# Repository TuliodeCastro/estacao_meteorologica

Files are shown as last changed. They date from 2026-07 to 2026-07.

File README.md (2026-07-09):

# 🌦️ Estação Meteorológica com LoRa

Sistema de monitoramento climático distribuído usando **ESP8266, LoRa, Sensores** e **Firebase** para registro de dados em nuvem.

## 📋 Visão Geral

Um projeto de IoT que coleta dados meteorológicos (temperatura, pressão, umidade, vento, chuva, radiação solar) em um **nó sensor remoto** e os transmite via **LoRa** para um **gateway central**, que envia os dados para o **Firebase Realtime Database**.

### Arquitetura
```
Node Sensor (ESP8266)
  ├─ BME280 (temperatura, pressão, umidade)
  ├─ Anemômetro (velocidade do vento)
  ├─ Pluviômetro (medição de chuva)
  ├─ ADS1115 ADC (direção do vento, irradiância)
  └─ LoRa (transmissor)
          ↓ LoRa Transmission
        Gateway (ESP8266)
          ├─ LoRa (receptor)
          ├─ Wi-Fi
          └─ Firebase Client
                ↓
        📊 Firebase Realtime Database (Nuvem)
```

## 📁 Estrutura do Projeto

```
estacao_meteorologica/
├── README.md                          (este arquivo)
├── SETUP.md                           (instruções de configuração)
├── LICENSE                            (licença do projeto)
├── .gitignore                         (ignora arquivos sensíveis)
│
├── docs/
│   ├── HARDWARE.md                   (pinagem, componentes, esquemático)
│   ├── ARCHITECTURE.md               (fluxo de dados, protocolos)
│   └── DEPLOYMENT.md                 (guia de produção)
│
└── firmware/
    ├── README.md                     (documentação do firmware)
    ├── SECURITY_GUIDELINES.md        (boas práticas de segurança)
    │
    ├── gateway_lora/                 (receptor LoRa + Wi-Fi + Firebase)
    │   ├── src/main.cpp
    │   ├── include/credentials.h     (credenciais - NÃO COMMITAR)
    │   ├── include/credentials.h.example
    │   ├── SECURITY.md
    │   └── platformio.ini
    │
    └── node_sensor/                  (sensor remoto com LoRa)
        ├── src/main.cpp
        ├── include/
        ├── platformio.ini
        └── test/

```

## 🔧 Módulos

### Node Sensor (`firmware/node_sensor/`)
- **Placa:** D1 R2 Mini (ESP8266)
- **Sensores:**
  - BME280 (I2C): Temperatura, Pressão, Umidade
  - ADS1115 (I2C): Entrada analógica para piranômetro e direção
  - Anemômetro (GPIO): Sensor de efeito Hall
  - Pluviômetro (GPIO): Sensor de chuva
- **Ciclo:** Amostra a cada 5s por 2 min, transmite CSV via LoRa, dorme por 3 min

### Gateway LoRa (`firmware/gateway_lora/`)
- **Placa:** NodeMCU V2 (ESP8266)
- **Conectividade:**
  - LoRa (SoftwareSerial): Recebe dados do nó sensor
  - Wi-Fi: Conexão à rede local
  - Firebase: Envia dados para nuvem
- **Funcionalidade:** Recebe CSV do sensor, valida checksum, envia para Firebase

## 📊 Formato de Dados

**CSV transmitido pelo sensor:**
```
temp,pres,umid,pulsos,chuva,velMS,rajada,dir,irrad*CHECKSUM
25.5,1013.2,65.3,120,0.25,2.14,3.45,180,450.2*AB
```

| Campo | Descrição | Unidade |
|---|---|---|
| temp | Temperatura média | °C |
| pres | Pressão média | hPa |
| umid | Umidade relativa média | % |
| pulsos | Contagem de pulsos do vento | - |
| chuva | Acumulado de chuva | mm |
| velMS | Velocidade média do vento | m/s |
| rajada | Velocidade máxima (rajada) | m/s |
| dir | Direção média do vento | graus (0-360°) |
| irrad | Irradiância solar média | W/m² |

## 📚 Documentação

- **[SETUP.md](./SETUP.md)** — Como configurar e fazer upload do firmware
- **[docs/HARDWARE.md](./docs/HARDWARE.md)** — Pinagem, componentes, esquemático
- **[docs/ARCHITECTURE.md](./docs/ARCHITECTURE.md)** — Fluxo de dados e protocolos
- **[firmware/SECURITY_GUIDELINES.md](./firmware/SECURITY_GUIDELINES.md)** — Boas práticas de segurança
- **[firmware/gateway_lora/SECURITY.md](./firmware/gateway_lora/SECURITY.md)** — Configuração de credenciais

## 🛠️ Troubleshooting

### Sensor não transmite dados
1. Verifique conexão LoRa (pinos D6/D7)
2. Verifique sensor BME280 no Serial Monitor
3. Verifique poder do sensor (voltagem 3.3V)

### Gateway não recebe dados
1. Verifique Wi-Fi (Serial Monitor mostra IP?)
2. Verifique Firebase (credenciais corretas?)
3. Verifique potência LoRa (mesmos pinos)

### Firebase não recebe dados
1. Verifique credenciais em `credentials.h`
2. Verifique Firebase Rules permitem escrita anônima
3. Verifique conectividade Wi-Fi do gateway

Veja mais em **[docs/HARDWARE.md](./docs/HARDWARE.md)** e **[firmware/README.md](./firmware/README.md)**

## 📝 Licença

Este projeto está licenciado sob a [Licença MIT](./LICENSE).

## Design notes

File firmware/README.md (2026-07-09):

# 🔧 Firmware - Estação Meteorológica

Código embarcado para ESP8266 (Node Sensor e Gateway LoRa).

## 📂 Estrutura

```
firmware/
├── README.md                    (este arquivo)
├── SECURITY_GUIDELINES.md       (boas práticas de segurança)
│
├── gateway_lora/               (Receptor LoRa + Wi-Fi + Firebase)
│   ├── src/
│   │   └── main.cpp           (código principal ~270 linhas)
│   ├── include/
│   │   ├── credentials.h       (GITIGNORE - credenciais reais)
│   │   └── credentials.h.example
│   ├── platformio.ini          (configuração de build)
│   ├── SECURITY.md            (guia de segurança)
│   └── test/                  (testes)
│
└── node_sensor/               (Sensor remoto com LoRa)
    ├── src/
    │   └── main.cpp           (código principal ~270 linhas)
    ├── include/
    │   └── README
    ├── platformio.ini          (configuração de build)
    └── test/

## 📊 Módulos Explicados

### Node Sensor (`node_sensor/src/main.cpp`)

**Responsabilidade:** Coletar dados de sensores e transmitir via LoRa

**Fluxo:**
1. **Setup:** Inicializa sensores (BME280, ADS1115) e interrupções
2. **Janela Ativa (2 min):** Amostra sensores a cada 5s
   - BME280: temperatura, pressão, umidade
   - Anemômetro: pulsos do vento
   - Pluviômetro: pulsos de chuva
   - ADS1115: direção, irradiância
3. **Processamento:** Calcula médias e máximos
4. **Transmissão:** Monta CSV com checksum XOR e envia via LoRa
5. **Deep Sleep:** Dorme por 3 min (economia de bateria)

**Saída esperada (Serial @115200):**
```
=== ACORDOU — iniciando janela ativa ===
──── Médias da janela ──────────────────────
Temperatura: 25.3 °C
Pressão:     1013.2 hPa
Umidade:     65.4 %
Chuva:       0.00 mm
Vento médio: 1.23 m/s
Rajada (3s): 2.45 m/s
Direção:     180°
Irradiância: 450.2 W/m²
Amostras BME: 4
──── Payload enviado ───────────────────────
25.3,1013.2,65.4,0,0.00,1.23,2.45,180,450.2*AB
=== DORMINDO por 3 minutos ===
```

**Sensores:**
- **BME280** (I2C @ 0x76): Temperatura, Pressão, Umidade
- **ADS1115** (I2C @ 0x48): Entrada para piranômetro (A0-A1) e direção (A2)
- **Anemômetro** (GPIO0/D3): Sensor Hall com ISR debounce 5ms
- **Pluviômetro** (GPIO14/D5): Reed switch com ISR debounce 200ms

**Configurações Importantes:**
```cpp
const float PI_CONST = 3.14159265;
const int   RAIO     = 147;              // Raio do anemômetro (mm)

const unsigned long JANELA_ATIVA = 12000UL;  // 2 min ativo
const uint64_t       TEMPO_SONO   = 18e6;     // 3 min sleep

const float CAL_WM2_POR_MV = 5.0;  // TROCAR pelo certificado!
const float MM_POR_PULSO = 0.25;   // Calibração pluviômetro
```

### Gateway LoRa (`gateway_lora/src/main.cpp`)

**Responsabilidade:** Receber dados via LoRa, validar e enviar para Firebase

**Fluxo:**
1. **Setup:** Conecta Wi-Fi, inicializa Firebase, abre Serial LoRa
2. **Loop:**
   - Mantém Wi-Fi ativo (reconexão não-bloqueante)
   - Envia heartbeat a cada 15s
   - Recebe mensagens LoRa (buffer circular)
   - Valida checksum XOR
   - Envia para Firebase (com timestamp)

**Saída esperada (Serial @115200):**
```
Receptor LoRa (CSV) iniciado!
================================================
[WiFi] Conectado. IP: 192.168.1.100
Sincronizando hora via NTP
Hora sincronizada!
Firebase iniciado.
──── Mensagem recebida ─────────────────────────
Temperatura: 25.3 °C
Pressão:     1013.2 hPa
Umidade:     65.4 %
Chuva:       0.00 mm
Vento médio: 1.23 m/s
Rajada (3s): 2.45 m/s
Direção:     180°
Irradiância: 450.2 W/m²
================================================
[Firebase] Dados enviados!
[Heartbeat] OK.
```

**Dependências:**
- Firebase Arduino Client Library (v4.4.17+)
- ESP8266 Core

**Configurações Importantes:**
```cpp
const char* WIFI_SSID = "O sentido da vida, do universo e tudo mais";          // Vir de credentials.h
const char* WIFI_PASS = "42";      // Vir de credentials.h

#define FIREBASE_HOST    "..."              // Firebase URL
#define FIREBASE_API_KEY "..."              // Firebase API Key

const unsigned long INTERVALO_HEARTBEAT = 15000;  // 15s
```

## 🔐 Segurança

### Credenciais
- ✅ Armazenadas em `include/credentials.h` (não commitado)
- ✅ Template em `include/credentials.h.example`
- ✅ Protegidas por `.gitignore`

Ver: **[SECURITY_GUIDELINES.md](./SECURITY_GUIDELINES.md)**

### Firebase Rules
Configure no Firebase Console:
```json
{
  "rules": {
    "estacao": {
      "leituras": {
        ".write": "auth != null",
        ".read": "auth != null"
      },
      "status": {
        ".read": true,
        ".write": "auth != null"
      }
    }
  }
}
```

## 📦 Dependências

### Node Sensor (`platformio.ini`)
```ini
lib_deps =
    adafruit/Adafruit BME280 Library@^2.3.0
    adafruit/Adafruit ADS1X15@^2.6.2
```

### Gateway LoRa (`platformio.ini`)
```ini
lib_deps =
    mobizt/Firebase Arduino Client Library for ESP8266 and ESP32 @ ^4.4.17
```

## 🔧 Calibração

### Piranômetro (Irradiância Solar)

**Procedimento:**
1. Obter certificado de calibração do piranômetro
2. Encontrar coeficiente: µV/(W/m²)
3. Convertendo para mV/(W/m²): `CAL_WM2_POR_MV`

**Exemplo:**
- Certificado: 8.5 µV/(W/m²)
- Conversão: 8.5 µV = 0.0085 mV
- Inverso: 1 / 0.0085 = 117.6 W/m² / mV
- Usar: `CAL_WM2_POR_MV = 117.6`

### Pluviômetro

**Procedimento:**
1. Identificar volume por pulso do reed switch
2. Converter para mm de chuva

**Exemplo:**
- Funil area: 60 cm²
- Volume por pulso: 15 mL
- Chuva: 15 mL / 60 cm² = 0.25 mm
- Usar: `MM_POR_PULSO = 0.25`

### Anemômetro

**Fórmula no código:**
```cpp
float rpm = (pulsos * 60000.0) / intervaloMs;
float velocidade = ((4 * PI_CONST * RAIO * rpm) / 60.0) / 1000.0;
```

**Para seu anemômetro:**
1. Medir raio (distância do pino Hall até extremidade do copo)
2. Atualizar: `const int RAIO = 147;  // em mm`

## ⚙️ Configuração Avançada

### Mudar Frequência de Amostragem

```cpp
// Node Sensor - intervalos de amostragem
const unsigned long AMOSTRA_BME_MS = 5000;   // Aumentar para menos amostras
const unsigned long AMOSTRA_DIR_MS = 5000;
const unsigned long AMOSTRA_IRR_MS = 5000;
const unsigned long JANELA_RAJADA  = 3000;   // Janela de rajada (WMO: 3s)
```

### Mudar Tempo de Ciclo

```cpp
// Node Sensor - ciclo completo
const unsigned long JANELA_ATIVA = 12000UL;  // Aumentar para 24000 = 4 min
const uint64_t       TEMPO_SONO   = 18e6;     // Aumentar para 60e6 = 10 min
```

### Mudar Intervalo de Heartbeat

```cpp
// Gateway - heartbeat para status
const unsigned long INTERVALO_HEARTBEAT = 15000;  // Aumentar para 30000 = 30s
```

## 🐛 Debugging

### Aumentar Verbosidade

Adicione ao `main.cpp`:
```cpp
#define DEBUG_SERIAL Serial
// Ou
#define DEBUG_SERIAL Serial1
```

Use antes de Serial.print():
```cpp
DEBUG_SERIAL.println("Debug info");
```

### Verificar Memória

```cpp
Serial.print("Free Heap: ");
Serial.println(ESP.getFreeHeap());
```

### Verificar Voltagem

```cpp
Serial.print("Voltage: ");
Serial.println(analogRead(A0) / 1024.0 * 3.3);  // Apenas D1/D5 mini
```

## 📚 Referências

- [ESP8266 Arduino Core](https://github.com/esp8266/Arduino)
- [Adafruit BME280 Library](https://github.com/adafruit/Adafruit_BME280_Library)
- [Adafruit ADS1115 Library](https://github.com/adafruit/Adafruit_ADS1X15)
- [Firebase ESP8266 Client](https://github.com/mobizt/Firebase-ESP8266)
- [PlatformIO Documentation](https://docs.platformio.org/)

## 📝 Histórico de Versões

- **v1.0.0** (2026-07-09) - Versão inicial com suporte básico

---

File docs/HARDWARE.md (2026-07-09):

# 🔌 Hardware - Estação Meteorológica

Documentação completa de componentes, pinagem e esquemático.

## 📦 Componentes Utilizados

### Node Sensor

| Componente | Modelo | Quantidade | Interface | Voltagem |
|---|---|---|---|---|
| Microcontrolador | D1 R2 Mini (ESP8266) | 1 | SPI/I2C | 3.3V |
| Sensor Temp/Pres/Umid | BME280 | 1 | I2C | 3.3V |
| Conversor ADC | ADS1115 (16-bit) | 1 | I2C | 3.3V |
| Transmissor LoRa | E220-900T22D | 1 | UART | 3.3V |
| Anemômetro | Hall sensor (3 xícaras) | 1 | Digital (ISR) | 5V |
| Pluviômetro | Reed switch | 1 | Digital (ISR) | - |
| Piranômetro | Sensor analógico | 1 | Analógico (ADC) | 0-5V |
| Medidor de Direção | Potenciômetro 10kΩ | 1 | Analógico (ADC) | 0-5V |

### Gateway

| Componente | Modelo | Quantidade | Interface | Voltagem |
|---|---|---|---|---|
| Microcontrolador | NodeMCU V2 (ESP8266) | 1 | SPI/I2C | 3.3V |
| Receptor LoRa | E220-900T22D | 1 | UART | 3.3V |
| Conectividade | Wi-Fi (incorporado) | - | 802.11b/g/n | 3.3V |

## 🔌 Pinagem Detalhada

### D1 R2 Mini (Node Sensor)

```
       ┌─────────────────────────┐
  GND -│ ●                     ● │- GND
  RX  -│   D1 R2 Mini        5V │- 5V
  TX  -│   (ESP8266)         3V │- 3V3 (50mA)
  D8  -│ GPIO15            RST  │- RST
  D7  -│ GPIO13             A0  │- ADC (0-1V)
  D6  -│ GPIO12            3V3  │- 3V3
  D5  -│ GPIO14 (SCL)     CH_PD │- CH_PD (pull-up)
  D4  -│ GPIO2 (SDA)        D0  │- GPIO16 (WAKE)
  D3  -│ GPIO0 (INT)        D3  │- GPIO0 (RST/BOOT)
  D2  -│ GPIO4             TX   │- TX
  D1  -│ GPIO5 (SCL alt)   RX   │- RX
  D0  -│ GPIO16 (WAKE)          │
       └─────────────────────────┘
```

#### I2C (BME280 + ADS1115)
```
        D4 (GPIO2/SDA) ───┬─── BME280 SDA
                          ├─── ADS1115 SDA
                          └─── 10kΩ pull-up ─ 3.3V
        
        D5 (GPIO14/SCL) ──┬─── BME280 SCL
                          ├─── ADS1115 SCL
                          └─── 10kΩ pull-up ─ 3.3V
        
        GND ──────────────┬─── BME280 GND
                          ├─── ADS1115 GND
        
        3V3 ──────────────┬─── BME280 VCC
                          ├─── ADS1115 VDD
```

#### LoRa UART (SoftwareSerial)
```
        D6 (GPIO12) RX ─── LoRa TX
        D7 (GPIO13) TX ─── LoRa RX
        3V3 ────────────── LoRa VCC
        GND ────────────── LoRa GND
```

#### Sensores Digital (ISR)
```
        D3 (GPIO0)  ─── Anemômetro (Hall effect)
        D5 (GPIO14) ─── Pluviômetro (Reed switch)
```

#### Sensores Analógico (ADC via ADS1115)
```
        ADS1115 A0 ─── Piranômetro (0-5V)
        ADS1115 A1 ─── GND (ref)
        ADS1115 A2 ─── Medidor Direção (0-5V)
        ADS1115 A3 ─── NC (não usado)
```

### NodeMCU V2 (Gateway)

```
       ┌──────────────────────────┐
  GND -│ ●                      ● │- GND
  D0  -│ GPIO16               5V │- 5V
  D1  -│ GPIO5                3V │- 3V3
  D2  -│ GPIO4             RST/CH│- RST
  D3  -│ GPIO0              Vin  │- Vin
  D4  -│ GPIO2               D8  │- GPIO15
  D5  -│ GPIO14 (SCL)        D7  │- GPIO13 (TX)
  D6  -│ GPIO12 (RX)         D6  │- GPIO12 (RX)
  D7  -│ GPIO13 (TX)         D5  │- GPIO14 (SCL)
  D8  -│ GPIO15              D4  │- GPIO2 (SDA)
  RX  -│ RX (GPIO3)          D3  │- GPIO0
  TX  -│ TX (GPIO1)          D2  │- GPIO4
  GND -│ GND                 D1  │- GPIO5
       └──────────────────────────┘
```

#### LoRa UART (SoftwareSerial)
```
        D8 (GPIO15) RX ─── LoRa TX
        D7 (GPIO13) TX ─── LoRa RX
        3V3 ────────────── LoRa VCC
        GND ────────────── LoRa GND
```

## ⚡ Alimentação

### Node Sensor
- **Voltagem:** 3.3V (USB durante desenvolvimento)
- **Consumo médio:** ~50mA (em operação)
- **Consumo em deep sleep:** ~20µA
- **Bateria recomendada:** 12V chumbo-ácido

### Gateway
- **Voltagem:** 5V (via USB)
- **Consumo médio:** ~80mA (Wi-Fi + LoRa)
- **Fonte:** USB

## 📐 Calibração de Sensores

### BME280
- **Endereço I2C:** 0x76 (default) ou 0x77 (via jumper)
- **Calibração:** Interna (factory calibration)
- **Verificação:** Comparar com termômetro de referência

### ADS1115
- **Endereço I2C:** 0x48 (GND), 0x49 (VDD), 0x4A (SDA), 0x4B (SCL)
- **Resolução:** 16 bits
- **Ganho:** GAIN_SIXTEEN (0.256V full scale) para sensores de baixa voltagem

### Piranômetro
- **Tipo:** Sensor analógico com fotodiodo
- **Saída:** 0-5V → 0-1023 (ADS1115 com referência)
- **Calibração:** Usar certificado do fabricante
- **Fórmula:** Irradiância (W/m²) = Voltagem (mV) × CAL_WM2_POR_MV

### Pluviômetro
- **Tipo:** Reed switch (pulso por volume fixo)
- **Volume por pulso:** Tipicamente 0.2-0.5 mm
- **Calibração:** Medir volume real do funil

### Anemômetro
- **Tipo:** 3 xícaras com sensor Hall
- **Raio:** 147mm (deve ser medido no seu aparelho)
- **Conversão:** rpm → m/s usando fórmula de circunferência

### Medidor de Direção
- **Tipo:** Potenciômetro 10kΩ acoplado
- **Saída:** 0-5V → 8 direções (N, NE, E, SE, S, SO, O, NO)
- **Calibração:** Alinhar com bússola em 4 pontos cardinais

## 🔧 Montagem Física

### Posicionamento da Estação
- **Altura:** Mínimo 2m acima de obstáculos
- **Exposição:** Área aberta, longe de prédios/árvores
- **Proteção:** Abrigo de radiação (Stevenson screen) recomendado
- **Orientação:** Anemômetro/direção com N apontando para Norte verdadeiro

### Proteção Contra Intempéries
- **Enclosure:** Caixa plástica IP65 para circuitos
- **Antena LoRa:** Vertical, 1m de altura
- **Antena Wi-Fi:** Interna ou externa conforme sinal

## 🌐 Alcance LoRa

- **Teórico:** 10+ km em linha de visada
- **Prático:** 100-500m em ambiente urbano/indoor
- **Fatores:** Antena, potência, frequência, obstáculos

**Para aumentar alcance:**
- Elevar antena do transmissor
- Elevar antena do receptor
- Remover obstáculos entre eles
- Usar antena omnidirecional de melhor qualidade

## 📚 Datasheets

- [BME280](https://www.bosch-sensortec.com/products/bme280/)
- [ADS1115](https://www.ti.com/product/ADS1115)
- [E220-900T22D](https://www.cdebyte.com/products/E220-900T22D/2#Pin)
- [ESP8266](https://www.espressif.com/en/products/microcontrollers/esp8266)

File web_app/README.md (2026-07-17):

# 🌦️ Estação Meteorológica IoT — UFOP

Site de visualização em tempo real dos dados da estação meteorológica IoT
desenvolvida por estudantes de **Engenharia de Controle e Automação da UFOP**.

Projetado para rodar em **totem interativo com tela touch** (orientação
vertical), além de TVs e dispositivos móveis.

> Desenvolvido por **Altamiro Marcos Ferreira Neto**, **Túlio Leandro de Castro**
> e **Gustavo de Oliveira Morais**
> Departamento de Engenharia de Controle e Automação — UFOP

---

## 🚀 Como rodar

```bash
npm install        # instala as dependências (só na primeira vez)
npm run dev        # servidor de desenvolvimento → http://localhost:5173
npm run build      # gera a versão final na pasta dist/
npm run preview    # testa a versão final localmente
```

Para o totem, gere o build (`npm run build`) e sirva a pasta `dist/` em
qualquer servidor estático. Abra o navegador em **modo quiosque**:

```bash
chrome --kiosk --noerrdialogs --disable-pinch http://localhost:5173
```

## 🧱 Stack

| Tecnologia | Uso |
|---|---|
| React + Vite | interface e empacotamento |
| Firebase Realtime Database | leitura dos dados em tempo real (`onValue`) |
| Tailwind CSS | estilização (glassmorphism, animações) |
| Recharts | gráficos das leituras |

## 📡 Dados

Conectado a `https://estacao-meteorologica-479ce-default-rtdb.firebaseio.com`,
caminho `/estacao/leituras`. Campos: `temp` (°C), `pres` (hPa), `umid` (%),
`pulsos`, `chuva` (mm), `rpm`, `velMS` (m/s), `velKMH` (km/h), `dir` (graus),
`direcao` (texto), `irrad` (W/m²). As leituras chegam a cada ~2 minutos.

## 🗂️ Estrutura do código (tudo comentado em português!)

```
src/
├── main.jsx                  → entrada + proteções de quiosque + auto-recuperação
├── App.jsx                   → navegação por seções, fundo dinâmico, modo atrativo
├── firebase.js               → conexão com o Firebase + reconexão forçada
├── index.css                 → estilos globais, animações CSS, fundos por clima
├── hooks/
│   ├── useEstacao.js         → escuta o Firebase, histórico, vigia de reconexão
│   └── useInatividade.js     → detecta inatividade (modo atrativo / limpeza do chat)
├── utils/
│   └── clima.js              → condição do céu, frases didáticas, formatação
└── components/
    ├── Hero.jsx              → título + status "🟢 Ao vivo"
    ├── PainelCards.jsx       → cards gigantes com os dados dos sensores
    ├── IconesAnimados.jsx    → SVGs animados (cata-vento gira com o vento real!)
    ├── ComoFunciona.jsx      → diagrama interativo sensores→LoRa→Firebase→site
    ├── Meteorinho.jsx        → chatbot (Claude API + cérebro local de reserva)
    ├── TecladoVirtual.jsx    → teclado na tela para o totem
    ├── Graficos.jsx          → gráficos Recharts com seletor por botões
    ├── ModoAtrativo.jsx      → descanso de tela após 2 min sem toque
    ├── ParticulasChuva.jsx   → chuva na tela quando chove de verdade 🌧️
    ├── CeuEstrelado.jsx      → estrelas no modo noite ✨
    ├── Rodape.jsx            → créditos e logos (placeholders)
    └── ErrorBoundary.jsx     → tela de erro com reinício automático
```

## ⚙️ Comportamentos importantes do totem

- **Modo atrativo**: após 2 min sem toque, mostra os dados em fonte gigante
  com o convite "👋 Toque na tela para explorar!". Qualquer toque sai.
- **Chat com privacidade**: a conversa do Meteorinho é apagada após 1 min
  sem interação.
- **Quiosque**: zoom por pinça/duplo toque bloqueado, seleção de texto
  desativada, sem links externos, botão 🏠 Início sempre visível.
- **Resiliência**: se o Firebase cair, mostra os últimos dados com aviso
  discreto; se nenhuma leitura chegar em 10 min, força reconexão; se o site
  quebrar, recarrega sozinho em 10 s.
- **Fundo dinâmico**: ensolarado / nublado / chuvoso / noite conforme
  `irrad` e `chuva` reais (limiares em `src/utils/clima.js`).

## 🤖 Chatbot Meteorinho

Se `window.claude.complete` (API da Anthropic) estiver disponível no
ambiente, as perguntas vão para o Claude com os dados atuais como contexto.
Caso contrário, um **cérebro local** responde com base em palavras-chave e
nos dados reais — o totem nunca fica sem resposta.

## 🖼️ Logos

Os quadrados "UFOP" e "DECAT" no rodapé ([Rodape.jsx](src/components/Rodape.jsx))
são placeholders — basta substituí-los por `<img>` com os arquivos oficiais.

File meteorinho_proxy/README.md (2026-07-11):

# 🌩️ Meteorinho Proxy (Cloudflare Worker)

Backend minúsculo e **gratuito** que faz a ponte entre o site da estação
(público) e a **API da NVIDIA**, mantendo a chave de API **em segredo**.

Por que existe: o site é estático e público. Se a chave da NVIDIA ficasse no
código do site, qualquer visitante poderia lê-la (na aba "Rede" do navegador) e
usá-la. Além disso, a API da NVIDIA bloqueia chamadas diretas do navegador
(CORS). Este Worker resolve os dois problemas: a chave fica guardada nele, e o
site conversa só com o Worker.

```
Site (Meteorinho)  →  Cloudflare Worker  →  API da NVIDIA
     (público)         (chave em segredo)     (integrate.api.nvidia.com)
```

## Pré-requisitos
- Uma conta **Cloudflare** (grátis): https://dash.cloudflare.com/sign-up
- **Node.js** instalado (já usado no site)
- Sua **chave da NVIDIA** (começa com `nvapi-...`), obtida em
  https://build.nvidia.com/ → em qualquer modelo, botão **Get API Key**

## Como publicar (uma vez)

Dentro desta pasta (`meteorinho_proxy/`):

```bash
# 1) Fazer login na Cloudflare (abre o navegador)
npx wrangler login

# 2) Guardar a chave da NVIDIA como SEGREDO (ela NÃO vai para o repositório!)
npx wrangler secret put NVIDIA_API_KEY
#    → cole a chave nvapi-... quando pedir e tecle Enter

# 3) Publicar o Worker
npx wrangler deploy
```

No fim, o comando mostra a URL pública do Worker, algo como:

```
https://meteorinho-proxy.SEU-SUBDOMINIO.workers.dev
```

## Conectar ao site
Copie essa URL e cole em [`web_app/src/config.js`](../web_app/src/config.js):

```js
export const URL_METEORINHO = 'https://meteorinho-proxy.SEU-SUBDOMINIO.workers.dev';
```

Depois rebuilde e publique o site (`npm run build` + `firebase deploy` na
pasta `web_app/`). Pronto — o Meteorinho passa a responder com a NVIDIA. Se o
Worker estiver fora do ar ou a `URL_METEORINHO` estiver vazia, o site usa
automaticamente o "cérebro local" (respostas prontas), então o totem nunca fica
sem resposta.

## Ajustes
- **Modelo**: edite a constante `MODELO` no [`worker.js`](worker.js).
- **Domínios autorizados**: a lista `ORIGENS_PERMITIDAS` no `worker.js` controla
  quais sites podem usar o proxy. Adicione o domínio final do totem se mudar.
- **Trocar a chave**: rode de novo `npx wrangler secret put NVIDIA_API_KEY`.

> ⚠️ A chave da NVIDIA **nunca** deve ser commitada. Ela vive só como *secret*
> do Worker — do mesmo jeito que o `credentials.h` do firmware fica fora do
> repositório.

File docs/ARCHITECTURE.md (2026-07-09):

# 🏗️ Arquitetura - Estação Meteorológica

Visão geral da arquitetura do sistema, fluxo de dados e componentes.

## 📊 Visão Geral

```
┌─────────────────┐
│  Node Sensor    │
│  (Remoto)       │
│                 │
│ - BME280        │
│ - ADS1115       │
│ - Anemômetro    │
│ - Pluviômetro   │
│ - Piranômetro   │
│                 │
│ [ESP8266]       │
│  ├─ I2C (I²C)   │
│  ├─ GPIO (INT)  │
│  └─ UART (LoRa) │
└────────┬────────┘
         │
         │ LoRa (1278 TX)
         │ CSV + Checksum
         │ ~100m range
         │
         ▼
┌─────────────────┐
│  Gateway LoRa   │
│  (Central)      │
│                 │
│ [ESP8266]       │
│  ├─ UART (LoRa) │
│  ├─ Wi-Fi       │
│  └─ Firebase    │
│                 │
│ - RX Parser     │
│ - Checksum Val  │
│ - Firebase Push │
└────────┬────────┘
         │
         │ HTTP(S)
         │ (Porta 443)
         │
         ▼
    ☁️ Firebase
   Realtime DB
   (Nuvem Google)
```

## 🔄 Fluxo de Dados

### 1. Node Sensor - Ciclo de Amostragem (2 min ativo + 3 min sleep)

```
┌─────────────────────────────────────────────────────────────┐
│                    NODE SENSOR                              │
├─────────────────────────────────────────────────────────────┤
│                                                               │
│  [Acordar do Deep Sleep]                                     │
│           ↓                                                   │
│  [Inicializar Sensores]                                      │
│   └─ BME280, ADS1115, ISRs                                   │
│           ↓                                                   │
│  ┌─────────────────────────────────────────┐                │
│  │   JANELA ATIVA: 2 min (amostragem)       │                │
│  │                                          │                │
│  │  A cada 5s:                             │                │
│  │  ├─ BME280.read() → T, P, U             │                │
│  │  ├─ ADS1115.read(A0, A2) → Irr, Dir     │                │
│  │  └─ Acumula: temp, pres, umid, irrad    │                │
│  │                                          │                │
│  │  A cada 3s (rajada):                    │                │
│  │  ├─ Calcula v(rajada)                   │                │
│  │  └─ Guarda máximo                       │                │
│  │                                          │                │
│  │  ISRs contínuos:                        │                │
│  │  ├─ Anemômetro → hallCountTotal         │                │
│  │  ├─ Anemômetro → hallCountRajada        │                │
│  │  └─ Pluviômetro → reedCount             │                │
│  └─────────────────────────────────────────┘                │
│           ↓                                                   │
│  [Calcular Médias]                                           │
│   ├─ Temp, Pres, Umid    = Σ / n                            │
│   ├─ Vento médio          = pulsos/tempo                    │
│   ├─ Rajada máx           = máximo guardado                 │
│   ├─ Direção média        = atan2(Σsin, Σcos)               │
│   ├─ Chuva acumulada      = reedCount × MM_POR_PULSO        │
│   └─ Irradiância média    = Σ / n                           │
│           ↓                                                   │
│  [Montar Payload CSV]                                        │
│   ├─ temp,pres,umid,pulsos,chuva,                          │
│   ├─ velMS,rajada,dir,irrad                                │
│   ├─ Calcular Checksum XOR                                  │
│   └─ CSV = "25.3,1013.2,65.4,120,0.25,1.23,2.45,180,450.2*AB"  │
│           ↓                                                   │
│  [Transmitir via LoRa]                                       │
│   └─ loraSerial.println(payload)                            │
│           ↓                                                   │
│  [Aguardar 200ms]                                            │
│   └─ Dar tempo para LoRa terminar TX                        │
│           ↓                                                   │
│  [Deep Sleep por 3 min]                                      │
│   └─ ESP.deepSleep(18e6) // Economia de bateria             │
│           ↓                                                   │
│  [Acordar] → Voltar ao início                                │
│                                                               │
└─────────────────────────────────────────────────────────────┘
```

### 2. Gateway - Recepção e Envio

```
┌─────────────────────────────────────────────────────────────┐
│                     GATEWAY                                  │
├─────────────────────────────────────────────────────────────┤
│                                                               │
│  [Setup]                                                      │
│   ├─ Conectar Wi-Fi (SSID, PASS)                            │
│   ├─ Configurar NTP (sincronizar hora)                       │
│   ├─ Inicializar Firebase                                    │
│   └─ Abrir Serial LoRa (9600 baud)                          │
│           ↓                                                   │
│  ┌──────────────────────────────────┐                       │
│  │  LOOP PRINCIPAL (não-bloqueante)  │                       │
│  │                                   │                       │
│  │  ├─ Garantir Wi-Fi               │ (a cada 5s)           │
│  │  │  (reconexão automática)        │                       │
│  │  │                                │                       │
│  │  ├─ Inicializar Firebase         │ (1x na boot/reconexão)│
│  │  │  (signUp anônimo)              │                       │
│  │  │                                │                       │
│  │  ├─ Enviar Heartbeat             │ (a cada 15s)          │
│  │  │  (status/timestamp)            │                       │
│  │  │                                │                       │
│  │  ├─ Receber LoRa                 │ (contínuo)            │
│  │  │  ┌──────────────────────────┐ │                       │
│  │  │  │ Enquanto loraSerial.available():│                   │
│  │  │  │   ├─ Ler char (c)       │ │                       │
│  │  │  │   ├─ Ignorar '\r'       │ │                       │
│  │  │  │   ├─ Se '\n': processar │ │                       │
│  │  │  │   ├─ Else: buffer(rxPos++)│                       │
│  │  │  └─ Validar chars printáveis│ │                       │
│  │  │                                │                       │
│  │  └─ Processar Mensagem            │                       │
│  │      ┌────────────────────────┐  │                       │
│  │      │ 1. Encontrar '*' (sep) │  │                       │
│  │      │ 2. Calcular Checksum   │  │                       │
│  │      │ 3. Comparar com receb. │  │                       │
│  │      │ 4. Se OK: parsear CSV  │  │                       │
│  │      │ 5. Enviar Firebase     │  │                       │
│  │      └────────────────────────┘  │                       │
│  │                                   │                       │
│  └──────────────────────────────────┘                       │
│           ↓                                                   │
│  [Envio Firebase]                                            │
│   ├─ /estacao/leituras/temp      ← float                   │
│   ├─ /estacao/leituras/pres      ← float                   │
│   ├─ /estacao/leituras/umid      ← float                   │
│   ├─ /estacao/leituras/chuva     ← float                   │
│   ├─ /estacao/leituras/velMS     ← float                   │
│   ├─ /estacao/leituras/rajada    ← float                   │
│   ├─ /estacao/leituras/dir       ← int                     │
│   ├─ /estacao/leituras/direcao   ← string (N/NE/E/...)    │
│   ├─ /estacao/leituras/irrad     ← float                   │
│   ├─ /estacao/leituras/timestamp ← int (unix)              │
│   └─ /estacao/status/ultimoHeartbeat ← int (unix)          │
│           ↓                                                   │
│  [Aguardar próxima mensagem]                                 │
│   └─ Voltar ao LOOP                                         │
│                                                               │
└─────────────────────────────────────────────────────────────┘
```

## 📡 Protocolo LoRa

### Formato da Mensagem

```
CSV PAYLOAD (com checksum XOR):
┌──────────────────────────────────────────────────────────────┐
│ temp,pres,umid,pulsos,chuva,velMS,rajada,dir,irrad*CHECKSUM │
└──────────────────────────────────────────────────────────────┘
      └─────── Campos de dados ───┘           └── Validação ──┘

Exemplo:
25.3,1013.2,65.4,120,0.25,1.23,2.45,180,450.2*AB
```

### Cálculo do Checksum

```cpp
// XOR de todos os caracteres dos dados
uint8_t cs = 0;
for (char c in "25.3,1013.2,65.4,120,0.25,1.23,2.45,180,450.2") {
    cs ^= c;  // XOR acumulativo
}
// cs = 0xAB (exemplo)
```

**Vantagens:**
- ✅ Simples computacionalmente
- ✅ Detecta erros de corrupção
- ✅ Não garante integridade (não é criptográfico)

## 🗄️ Firebase Database Structure

```
estacao_meteorologica-479ce/
│
├── estacao/
│   ├── leituras/                    (última medição)
│   │   ├── temp: 25.3              (°C)
│   │   ├── pres: 1013.2            (hPa)
│   │   ├── umid: 65.4              (%)
│   │   ├── pulsos: 120             (contagem)
│   │   ├── chuva: 0.25             (mm)
│   │   ├── velMS: 1.23             (m/s)
│   │   ├── rajada: 2.45            (m/s)
│   │   ├── dir: 180                (graus)
│   │   ├── direcao: "Sul"          (string)
│   │   ├── irrad: 450.2            (W/m²)
│   │   └── timestamp: 1688745600   (unix)
│   │
│   └── status/
│       ├── online: true
│       └── ultimoHeartbeat: 1688745615
```

## 🔐 Segurança

### Autenticação Firebase
```
Tipo: Anônimo
├─ Usuário sem e-mail/senha
├─ UID único atribuído
└─ Baseado em Firebase Rules
```

### Firebase Rules (Recomendadas)
```json
{
  "rules": {
    "estacao": {
      "leituras": {
        ".write": "auth != null",
        ".read": "auth != null"
      },
      "status": {
        ".write": "auth != null",
        ".read": true
      }
    }
  }
}
```

### Wi-Fi
- ✅ WPA2-PSK (senha segura)
- ✅ Armazenada em `credentials.h` (não commitado)
- ⚠️ Sem criptografia entre sensor e gateway (LoRa)

## ⚡ Timings

### Node Sensor

| Evento | Duração | Notas |
|---|---|---|
| Acordar | 1s | Boot ESP8266 |
| Init sensores | 500ms | I2C scan |
| Amostragem | 2 min | 24 amostras × 5s |
| Cálculo | 100ms | Processamento |
| Transmissão LoRa | 50ms | 9600 baud |
| Delay | 200ms | Deixar LoRa terminar |
| Deep sleep | 3 min | Economia de bateria |
| **Total ciclo** | **~5 min** | **Repetição** |

### Gateway

| Evento | Frequência | Notas |
|---|---|---|
| Wi-Fi check | 5s | Se desconectado, reconecta |
| Heartbeat | 15s | Status e timestamp |
| Recepção LoRa | Contínua | Buffer circular |
| Firebase push | Ao receber | Quando valida mensagem |

## 🔗 Dependências de Comunicação

```
Node Sensor              Gateway LoRa
├─ I2C Bus               ├─ UART (LoRa RX)
│  ├─ 0x76 (BME280)      └─ UART (LoRa TX)
│  └─ 0x48 (ADS1115)     
├─ GPIO (ISRs)
├─ UART (LoRa TX)
└─ 3.3V Power

Frequência LoRa: 915 MHz (Brasil) ou 868 MHz (Europa)
Baud rate: 9600
Alcance: ~100m (urbano), 500m+ (linha visada)
```

## 📈 Escalabilidade

### Múltiplos Sensores

Para adicionar mais nós sensores:

1. **Hardware:**
   - Adicionar novo D1 R2 Mini + sensores
   - LoRa TX na mesma frequência

2. **Firmware:**
   - Node Sensor: sem mudanças (TX continua igual)
   - Gateway: buffer LoRa permite múltiplas mensagens

3. **Firebase:**
   - Adicionar novo path: `/estacao/leituras/sensor2/`
   - Ou: `/sensores/{sensor_id}/leituras/`

4. **Parser Gateway:**
   - Identificar sender (não implementado no v1)
   - Recomendado para v2: adicionar ID na mensagem CSV

## 🎯 Fluxo Típico Completo

```
[T=0min] Node acorda
         ├─ Inicializa sensores
         └─ Começa amostragem

[T=2min] Termina amostragem
         ├─ Calcula médias
         ├─ Monta CSV
         ├─ Envia via LoRa
         └─ Dorme

[T=2min+50ms] Gateway recebe CSV
              ├─ Valida checksum ✅
              ├─ Parseia campos
              ├─ Envia para Firebase
              └─ Serial: "Dados enviados!"

[T=5min] Node acorda novamente
         └─ Ciclo se repete
```

## 📊 Consumo de Recursos

### Node Sensor
- **RAM:** ~30KB / 80KB disponível
- **ROM (Flash):** ~250KB / 1MB (D1 Mini)
- **Tempo boot:** ~1s

### Gateway
- **RAM:** ~50KB / 160KB disponível
- **ROM (Flash):** ~300KB / 4MB (NodeMCU)
- **Tempo boot:** ~2s

## 🔍 Monitoramento

### Logs via Serial
- **115200 baud**
- Sensor: mensagens de amostragem + payload
- Gateway: Wi-Fi, Firebase, heartbeat

### Firebase Console
- Dashboard em tempo real
- Histórico de dados
- Última atualização (timestamp)

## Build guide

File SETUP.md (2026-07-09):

# 🚀 Guia de Configuração - Estação Meteorológica

Este guia detalha como configurar, compilar e fazer upload do firmware nos boards ESP8266.

## 📋 Pré-requisitos

### Hardware
- ✅ **Node Sensor:** D1 R2 Mini (ESP8266)
- ✅ **Gateway:** NodeMCU V2 (ESP8266)
- ✅ **Sensor BME280** (I2C) - Node Sensor
- ✅ **Sensor ADS1115** (I2C) - Node Sensor
- ✅ **Módulo LoRa (E220-900T22D)** (UART) - Ambos
- ✅ **Anemômetro** (Hall sensor) - Node Sensor
- ✅ **Pluviômetro** (Reed switch) - Node Sensor
- ✅ **Conexão USB** para upload

### Software
- **VS Code** + extensão **PlatformIO** ([Instalar](https://platformio.org/install/ide?install=vscode))
- **Python 3.8+** (instalado automaticamente pelo PlatformIO)
- **Driver USB CH340** (se necessário) - [Download](https://www.wemos.cc/downloads)

## 📥 Instalação

### 1. Clone o Repositório

```bash
git clone <https://github.com/TuliodeCastro/estacao_meteorologica.git>
cd estacao_meteorologica
```

### 2. Abra no VS Code

```bash
code .
```

O PlatformIO vai inicializar automaticamente.

### 3. Configure Credenciais (Gateway)

```bash
cd firmware/gateway_lora
cp include/credentials.h.example include/credentials.h
```

**Edite `include/credentials.h` com:**
- Wi-Fi SSID e senha
- Firebase URL (seu banco de dados)
- Firebase API Key (gere no Firebase Console)

```cpp
#define WIFI_SSID "seu-ssid"
#define WIFI_PASS "sua-senha"
#define FIREBASE_HOST "https://seu-projeto-rtdb.firebaseio.com"
#define FIREBASE_API_KEY "AIzaSy..."
```

## 🔌 Conexão de Hardware

### Pinagem

#### Node Sensor (D1 R2 Mini)

| Sensor | Pino | GPIO | Protocolo |
|---|---|---|---|
| BME280 SDA | D4 | GPIO2 | I2C |
| BME280 SCL | D5 | GPIO14 | I2C |
| ADS1115 SDA | D4 | GPIO2 | I2C |
| ADS1115 SCL | D5 | GPIO14 | I2C |
| LoRa RX | D6 | GPIO12 | UART |
| LoRa TX | D7 | GPIO13 | UART |
| Anemômetro | D3 | GPIO0 | Digital (ISR) |
| Pluviômetro | D5 | GPIO14 | Digital (ISR) |

#### Gateway (NodeMCU V2)

| Sensor | Pino | GPIO | Protocolo |
|---|---|---|---|
| LoRa RX | D8 | GPIO15 | UART |
| LoRa TX | D7 | GPIO13 | UART |

## 💻 Compilação e Upload

### Opção 1: Via VS Code (Recomendado)

1. **Abra a paleta de comandos:** `Ctrl+Shift+P`

2. **Digite:** `PlatformIO: Build`
   - Ou clique no botão ✓ (Build) na barra inferior

3. **Aguarde a compilação**

4. **Conecte o board via USB**

5. **Digite:** `PlatformIO: Upload`
   - Ou clique no botão → (Upload) na barra inferior

6. **Aguarde o upload completar**

### Opção 2: Via Terminal

```bash
# Entrar no diretório
cd firmware/node_sensor   # ou gateway_lora

# Compilar
pio run

# Compilar + Upload
pio run --target upload

# Limpar build
pio run --target clean
```

## 🔍 Verificação

### 1. Abra o Serial Monitor

**VS Code:**
- Clique em "PlatformIO" na barra lateral
- Selecione "Serial Monitor"
- Ou `Ctrl+Alt+S`

**Velocidade:** 115200 baud

### 2. Node Sensor - Saída Esperada

```
=== ACORDOU — iniciando janela ativa ===
BME280 encontrado!
ADS1115 encontrado!
──── Médias da janela ──────────────────────
Temperatura: 25.3 °C
Pressão:     1013.2 hPa
Umidade:     65.4 %
Chuva:       0.00 mm
Vento médio: 1.23 m/s
Rajada (3s): 2.45 m/s
Direção:     180°
Irradiância: 450.2 W/m²
Amostras BME: 4
──── Payload enviado ───────────────────────
25.3,1013.2,65.4,0,0.00,1.23,2.45,180,450.2*XX
=== DORMINDO por 3 minutos ===
```

### 3. Gateway - Saída Esperada

```
Receptor LoRa (CSV) iniciado!
================================================
[WiFi] Conectado. IP: 424.242.4.242
Sincronizando hora via NTP
Hora sincronizada!
Criando usuário anônimo (única vez)...
Usuário anônimo criado!
Firebase iniciado.
──── Mensagem recebida ─────────────────────────
Temperatura: 25.3 °C
Pressão:     1013.2 hPa
...
================================================
[Firebase] Dados enviados!
[Heartbeat] OK.
```

## ⚠️ Troubleshooting

### "Placa não encontrada"
```
Solução:
1. Verifique conexão USB
2. Instale driver CH340 (https://www.wemos.cc/downloads)
3. Identifique a porta COM no Gerenciador de Dispositivos
4. Configure em platformio.ini: upload_port = COM3
```

### "Erro: Biblioteca não encontrada"
```
Solução:
1. Execute: pio run --target clean
2. Execute: pio pkg install
3. Reinicie VS Code
```

### "BME280 não encontrado!"
```
Verificar:
1. Conexão I2C (SDA=D4/GPIO2, SCL=D5/GPIO14)
2. Voltagem 3.3V no sensor
3. Pull-ups de 10kΩ na linha I2C (se necessário)
4. Endereço I2C: 0x76 (padrão) ou 0x77
```

### "ADS1115 não encontrado!"
```
Verificar:
1. Mesmos pinos I2C que BME280
2. Endereço I2C: 0x48 (padrão)
3. Pontes de seleção de endereço (ADDR pin)
```

### "LoRa não transmite"
```
Verificar:
1. Pinos UART corretos (RX=D6/GPIO12, TX=D7/GPIO13)
2. Velocidade serial: 9600 baud
3. Alimentação: mínimo 100mA @ 3.3V
4. Antena conectada e corretamente posicionada
```

### "Firebase não recebe dados"
```
Verificar:
1. Credenciais em credentials.h
2. Wi-Fi conectando (Serial Monitor)
3. Sincronização NTP (hora do sistema)
4. Firebase Rules permitem escrita anônima:
   "auth != null" no seu banco
5. Firewall/roteador bloqueando porta 443
```

### "Dados chegam ao Firebase mas incorretos"
```
Verificar:
1. Calibração: CAL_WM2_POR_MV (piranômetro)
2. Calibração: MM_POR_PULSO (pluviômetro)
3. Direção: Comparar com bússola real
```

## 🔧 Configurações Avançadas

### Aumentar Intervalo de Amostragem

**Node Sensor (`main.cpp`):**
```cpp
const unsigned long JANELA_ATIVA = 120000UL;  // 2 min - aumentar para 24000 = 4 min
const uint64_t TEMPO_SONO = 180e6;            // 3 min - aumentar para 60e6 = 10 min
```

### Mudar Endereço I2C do ADS1115

**Verificar jumper ADDR:**
- GND = 0x48 (padrão)
- VDD = 0x49
- SDA = 0x4A
- SCL = 0x4B

Atualizar no código se necessário.

## 📚 Referências

- [PlatformIO Documentation](https://docs.platformio.org/)
- [ESP8266 Arduino Reference](https://arduino-esp8266.readthedocs.io/)
- [BME280 Datasheet](https://www.bosch-sensortec.com/products/bme280/)
- [ADS1115 Datasheet](https://www.ti.com/product/ADS1115)
- [LoRa Protocol](https://lora-alliance.org/)
- [Firebase Documentation](https://firebase.google.com/docs)

## 📞 Suporte

Se encontrar problemas:
1. Consulte `docs/HARDWARE.md` para detalhes de pinagem
2. Consulte `firmware/README.md` para detalhes de código
3. Verifique logs no Serial Monitor (115200 baud)

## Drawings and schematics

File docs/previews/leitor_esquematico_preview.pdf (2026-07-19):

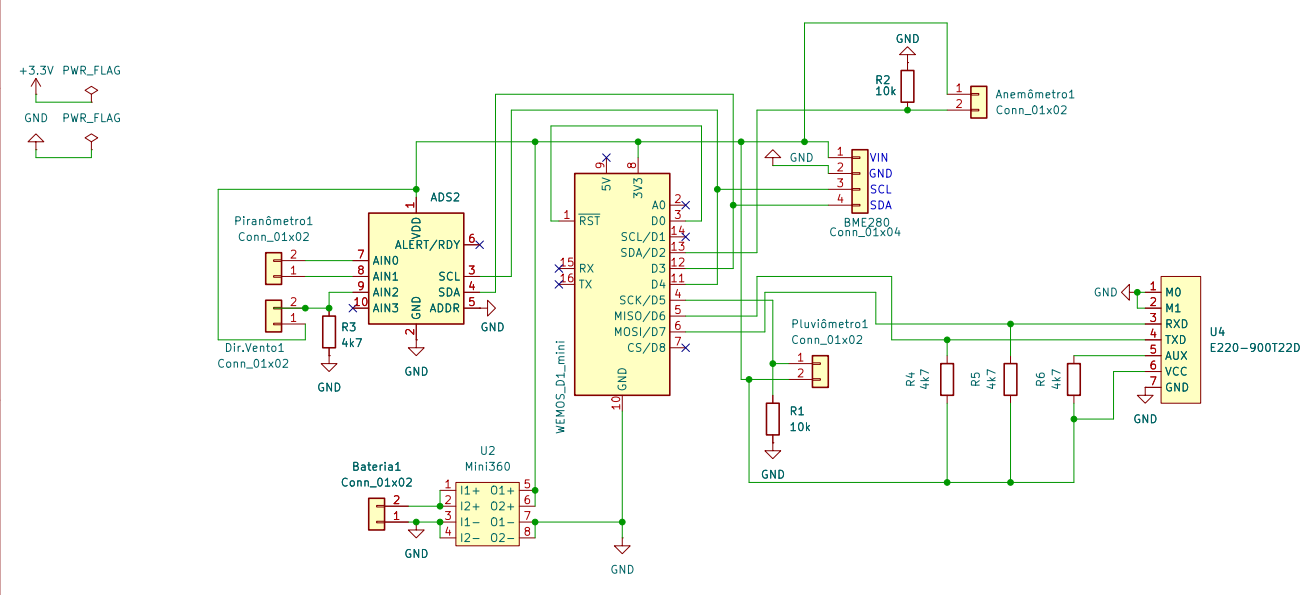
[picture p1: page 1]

8 5V 9 GND 10 D4 11 D3 12 SDA/D2 13 SCL/D1 14 RX 15

TXD 4
AUX 5

Size: A4 | Rev:
KiCad E.D.A. 10.0.3 | Id: 1/1

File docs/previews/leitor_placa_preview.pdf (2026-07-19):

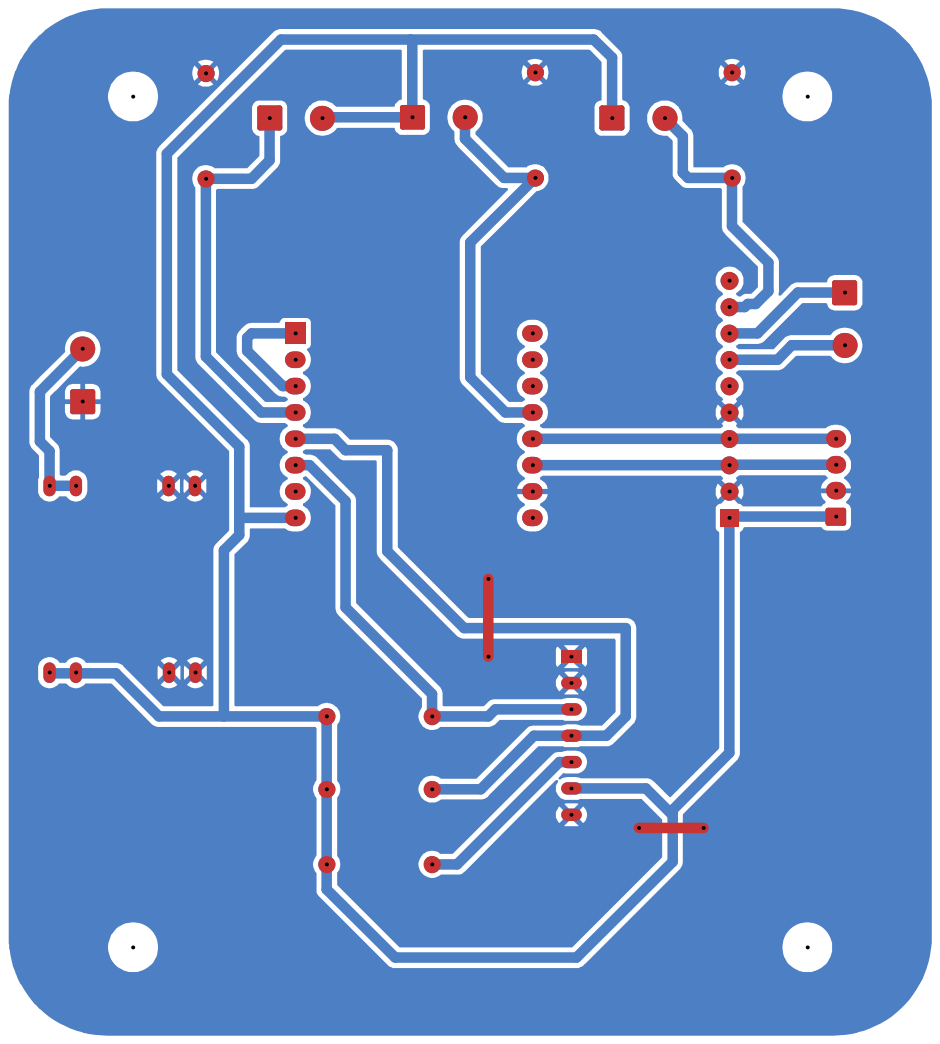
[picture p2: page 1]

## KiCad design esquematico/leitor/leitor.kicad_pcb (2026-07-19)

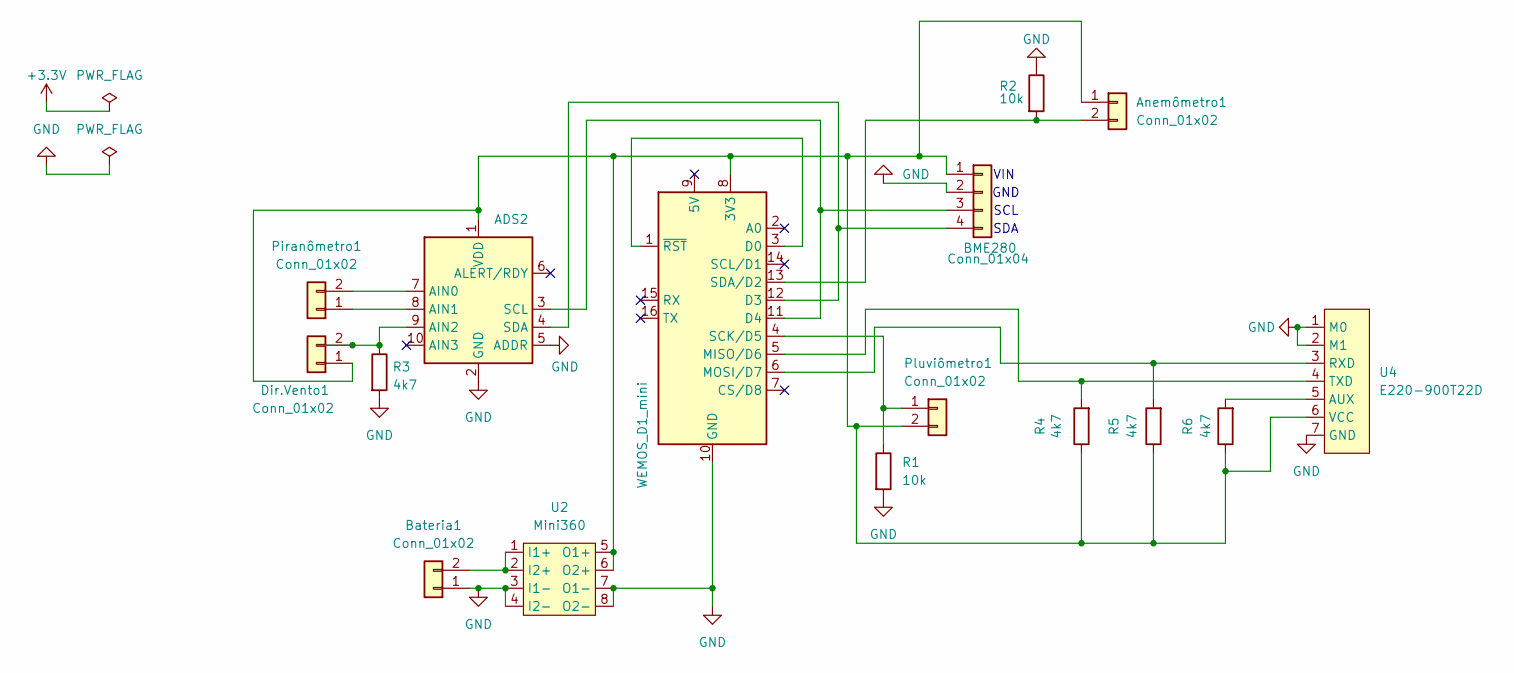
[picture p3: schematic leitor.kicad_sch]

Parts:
ADS2: ADS1115IDGS; ADS1115-VSSOP-28mmx17mm
Anemômetro1: Conn_01x02; TerminalBlock_CUI_TB007-508-02_1x02_P5.08mm_Horizontal
BME280: Conn_01x04; JST_XH_B4B-XH-A_1x04_P2.50mm_Vertical
Bateria1: Conn_01x02; TerminalBlock_CUI_TB007-508-02_1x02_P5.08mm_Horizontal
Dir.Vento1: Conn_01x02; TerminalBlock_CUI_TB007-508-02_1x02_P5.08mm_Horizontal
Piranômetro1: Conn_01x02; TerminalBlock_CUI_TB007-508-02_1x02_P5.08mm_Horizontal
Pluviômetro1: Conn_01x02; TerminalBlock_CUI_TB007-508-02_1x02_P5.08mm_Horizontal
R1, R2: 10k; R_Axial_DIN0207_L6.3mm_D2.5mm_P10.16mm_Horizontal
R3, R4, R5, R6: 4k7; R_Axial_DIN0207_L6.3mm_D2.5mm_P10.16mm_Horizontal
U1: WEMOS_D1_mini; WEMOS_D1_mini_light
U2: Mini360
U4: E220-900T22D

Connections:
GND: ADS2.2 (GND), ADS2.5 (ADDR), BME280.2, Bateria1.1, R1.2, R2.1, R3.2, U1.10 (GND), U2.3 (I1-), U2.4 (I2-), U2.7 (O1-), U2.8 (O2-), U4.1 (M0), U4.2 (M1), U4.7 (GND)
unnamed: ADS2.7 (AIN0), Piranômetro1.2
unnamed: ADS2.8 (AIN1), Piranômetro1.1
unnamed: ADS2.9 (AIN2), Dir.Vento1.2, R3.1
unnamed: ADS2.3 (SCL), BME280.3, U1.11 (D4)
unnamed: ADS2.4 (SDA), BME280.4, U1.12 (D3)
unnamed: ADS2.1 (VDD), Anemômetro1.1, BME280.1, Dir.Vento1.1, Pluviômetro1.2, R4.1, R5.1, R6.1, U1.8 (3V3), U2.5 (O1+), U2.6 (O2+), U4.6 (VCC)
unnamed: Anemômetro1.2, R2.2, U1.13 (SDA/D2)
unnamed: Bateria1.2, U2.1 (I1+), U2.2 (I2+)
unnamed: Pluviômetro1.1, R1.1, U1.4 (SCK/D5)
unnamed: U1.1 (~RST), U1.3 (D0)
unnamed: R4.2, U1.5 (MISO/D6), U4.4 (TXD)
unnamed: R5.2, U1.6 (MOSI/D7), U4.3 (RXD)
unnamed: R6.2, U4.5 (AUX)

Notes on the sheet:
VIN
GND
SCL
SDA

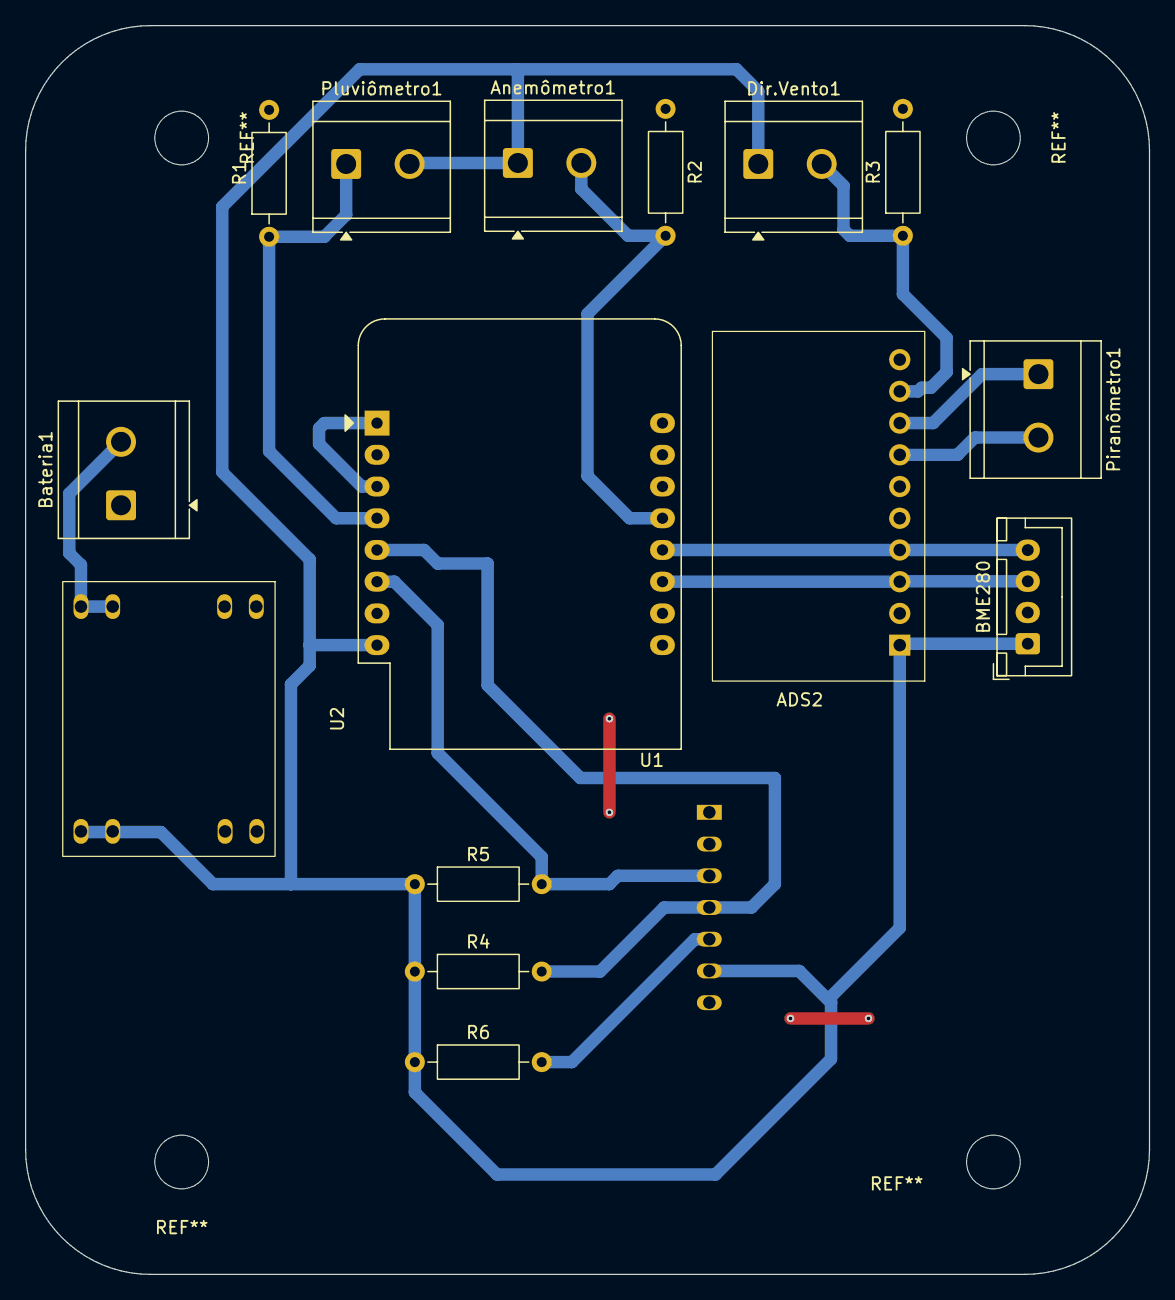
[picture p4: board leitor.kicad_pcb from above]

Board: 2 copper layers, 90.0 x 100.0 mm, 16 parts (1 on the bottom side), 14 nets.

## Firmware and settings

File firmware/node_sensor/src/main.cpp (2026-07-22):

#include <Arduino.h>

#include <Wire.h>
#include <Adafruit_BME280.h>
#include <Adafruit_ADS1X15.h>
#include <SoftwareSerial.h>
#include <ESP8266WiFi.h>
#include <math.h>

Adafruit_BME280 bme;
Adafruit_ADS1115 ads;
SoftwareSerial loraSerial(12, 13); // RX=D6(GPIO12), TX=D7(GPIO13)

// ─── Constantes gerais ───────────────────────────────────────────
const float PI_CONST = 3.14159265;
const int   RAIO     = 147;   // raio do anemômetro (mm)

// ─── Tempos do Caminho C ─────────────────────────────────────────
const unsigned long JANELA_ATIVA = 120000UL;  // 2 min amostrando
const uint64_t      TEMPO_SONO   = 180e6;     // 3 min em deep sleep (µs)

// Sub-intervalos de amostragem dentro da janela ativa
const unsigned long AMOSTRA_BME_MS = 5000;  // BME280 a cada 5 s
const unsigned long AMOSTRA_DIR_MS = 5000;  // direção a cada 5 s
const unsigned long AMOSTRA_IRR_MS = 5000;  // irradiância a cada 5 s
const unsigned long JANELA_RAJADA  = 3000;  // janela de rajada = 3 s (norma WMO)

// ─── Controle de qualidade (rejeição de outliers) ────────────────
const float LIMITE_VENTO_MS  = 50.0;   // acima de ~180 km/h é impossível aqui
const float FATOR_RAJADA_MAX = 3.0;    // rajada plausível é no máx ~3x a média
const float AUSENTE          = -999.0; // sentinela p/ leitura indisponível

// ─── Piranômetro ─────────────────────────────────────────────────
const float CAL_WM2_POR_MV = 5.0; // TROQUE pelo valor do seu certificado!

// ─── Pluviômetro ─────────────────────────────────────────────────
const int   REED         = 14;   // D5 = GPIO14 (Seguro - Mantido)
const float MM_POR_PULSO = 0.25;
volatile unsigned int reedCount = 0;

// ─── Anemômetro (por ISR no D2 = GPIO4) ──────────────────────────
const int HALL = 4;   // D2 = GPIO4 (Seguro - Remanejado)
volatile unsigned int hallCountTotal   = 0; // pulsos na janela inteira
volatile unsigned int hallCountRajada  = 0; // pulsos na sub-janela de 3 s

// ─── ISRs ────────────────────────────────────────────────────────
void IRAM_ATTR contaPulsoPluvio() {
  static unsigned long ultimoPulso = 0;
  unsigned long agora = millis();
  if (agora - ultimoPulso > 200) {
    reedCount++;
    ultimoPulso = agora;
  }
}

void IRAM_ATTR contaPulsoHall() {
  static unsigned long ultimoPulso = 0;
  unsigned long agora = millis();
  // debounce de 5ms — anemômetro pode girar rápido, então é curto
  if (agora - ultimoPulso > 5) {
    hallCountTotal++;
    hallCountRajada++;
    ultimoPulso = agora;
  }
}

// ─── Converte contagem de pulsos em velocidade (m/s) ─────────────
float pulsosParaMS(unsigned int pulsos, unsigned long intervaloMs) {
  if (intervaloMs == 0) return 0;
  float rpm = (pulsos * 60000.0) / intervaloMs;
  return ((4 * PI_CONST * RAIO * rpm) / 60.0) / 1000.0;
}

// ─── Direção via ADS1115 A2 → retorna em graus ───────────────────
int lerDirecaoGraus() {
  ads.setGain(GAIN_ONE);
  int16_t raw = ads.readADC_SingleEnded(2);
  float valor = ads.computeVolts(raw);

  if      (valor <= 0.18) return 315;
  else if (valor <= 0.21) return 270;
  else if (valor <= 0.25) return 225;
  else if (valor <= 0.30) return 180;
  else if (valor <= 0.38) return 135;
  else if (valor <= 0.50) return 90;
  else if (valor <= 0.83) return 45;
  else                    return 0;
}

// ─── Irradiância via ADS1115 A0-A1 (diferencial) ────────────────
float lerIrradiancia() {
  ads.setGain(GAIN_SIXTEEN);
  int16_t raw = ads.readADC_Differential_0_1();
  float mV = ads.computeVolts(raw) * 1000.0;
  if (mV < 0) mV = 0;
  return mV * CAL_WM2_POR_MV;
}

// ─── Monta CSV com checksum XOR ──────────────────────────────────
// Ordem dos campos: temp,pres,umid,pulsos,chuva,velMS,rajada,dir,irrad
String montarCSV(float temp, float pres, float umid,
                 unsigned int pulsos, float chuva,
                 float velMedia, float rajada,
                 int dir, float irrad) {
  String dados = String(temp, 1)     + "," +
                 String(pres, 1)     + "," +
                 String(umid, 1)     + "," +
                 String(pulsos)      + "," +
                 String(chuva, 2)    + "," +
                 String(velMedia, 2) + "," +
                 String(rajada, 2)   + "," +
                 String(dir)         + "," +
                 String(irrad, 1);

  // Checksum XOR de todos os caracteres dos dados
  uint8_t cs = 0;
  for (size_t i = 0; i < dados.length(); i++) {
    cs ^= dados[i];
  }

  char csHex[3];
  sprintf(csHex, "%02X", cs);

  return dados + "*" + csHex;
}

// ─────────────────────────────────────────────────────────────────
void setup() {
  // Desliga o Wi-Fi imediatamente — transmissor usa só LoRa
  WiFi.mode(WIFI_OFF);
  WiFi.forceSleepBegin();

  Serial.begin(115200);
  loraSerial.begin(9600);
  
  // I2C Remanejado para os pinos de boot (D3 e D4)
  // Eles possuem pull-up físico dos módulos BME e ADS, o que garante o boot perfeito.
  Wire.begin(0, 2); // SDA=D3(GPIO0), SCL=D4(GPIO2)

  Serial.println("\n=== ACORDOU — iniciando janela ativa ===");

  if (!bme.begin(0x76)) {
    Serial.println("BME280 não encontrado!");
  }
  if (!ads.begin(0x48)) {
    Serial.println("ADS1115 não encontrado!");
  }

  // Pluviômetro e anemômetro com interrupção em pinos 100% seguros
  pinMode(REED, INPUT_PULLUP);
  attachInterrupt(digitalPinToInterrupt(REED), contaPulsoPluvio, FALLING);

  pinMode(HALL, INPUT_PULLUP);
  attachInterrupt(digitalPinToInterrupt(HALL), contaPulsoHall, FALLING);

  // ── Acumuladores da janela ──────────────────────────────────────
  hallCountTotal = 0;
  reedCount      = 0;

  float somaTemp = 0, somaPres = 0, somaUmid = 0;
  int   nBme = 0;

  float somaIrr = 0;
  int   nIrr = 0;

  float somaSin = 0, somaCos = 0;
  int   nDir = 0;

  float rajadaMax = 0;

  unsigned long inicioJanela = millis();
  unsigned long ultBme = 0, ultDir = 0, ultIrr = 0, ultRajada = millis();

  // ── Loop da janela ativa (amostragem contínua) ──────────────────
  while (millis() - inicioJanela < JANELA_ATIVA) {
    unsigned long agora = millis();

    // BME280
    if (agora - ultBme >= AMOSTRA_BME_MS) {
      ultBme = agora;
      float t = bme.readTemperature();
      float p = bme.readPressure() / 100.0F;
      float u = bme.readHumidity();
      if (!isnan(t) && !isnan(p) && !isnan(u)) {
        somaTemp += t; somaPres += p; somaUmid += u; nBme++;
      }
    }

    // Direção (média vetorial)
    if (agora - ultDir >= AMOSTRA_DIR_MS) {
      ultDir = agora;
      int g = lerDirecaoGraus();
      float rad = g * PI_CONST / 180.0;
      somaSin += sin(rad);
      somaCos += cos(rad);
      nDir++;
    }

    // Irradiância
    if (agora - ultIrr >= AMOSTRA_IRR_MS) {
      ultIrr = agora;
      somaIrr += lerIrradiancia();
      nIrr++;
    }

    // Rajada — a cada 3s, calcula velocidade da sub-janela e guarda o pico
    if (agora - ultRajada >= JANELA_RAJADA) {
      noInterrupts();
      unsigned int pr = hallCountRajada;
      hallCountRajada = 0;
      interrupts();

      float vRajada = pulsosParaMS(pr, agora - ultRajada);
      if (vRajada > rajadaMax) rajadaMax = vRajada;
      ultRajada = agora;
    }

    yield(); // mantém o watchdog feliz
  }

  // ── Fim da janela — calcula resultados ──────────────────────────
  unsigned long duracao = millis() - inicioJanela;

  // Se o BME não leu nada na janela, marca como AUSENTE (não como 0!),
  // seguindo o princípio da OMM de sinalizar dado faltante.
  float temperatura = (nBme > 0) ? somaTemp / nBme : AUSENTE;
  float pressao     = (nBme > 0) ? somaPres / nBme : AUSENTE;
  float umidade     = (nBme > 0) ? somaUmid / nBme : AUSENTE;

  noInterrupts();
  unsigned int pulsosVento = hallCountTotal;
  unsigned int pulsosChuva = reedCount;
  interrupts();
  float velMedia = pulsosParaMS(pulsosVento, duracao);

  // ── QC do vento: descarta surtos espúrios do anemômetro ──────────
  // O sensor Hall pode gerar rajadas de pulsos falsos (repique/EMI) que
  // inflam a rajada para valores impossíveis (já medimos "441 km/h"!).
  // Rejeitamos rajada acima do limite físico OU muito maior que a média.
  if (velMedia > LIMITE_VENTO_MS) velMedia = 0;  // média impossível → descarta
  if (rajadaMax > LIMITE_VENTO_MS ||
      (velMedia > 0.5 && rajadaMax > velMedia * FATOR_RAJADA_MAX)) {
    rajadaMax = velMedia;                          // rajada espúria → usa a média
  }
  if (rajadaMax < velMedia) rajadaMax = velMedia;  // rajada nunca < média

  float chuva = pulsosChuva * MM_POR_PULSO;

  int dirMedia = 0;
  if (nDir > 0) {
    float ang = atan2(somaSin / nDir, somaCos / nDir) * 180.0 / PI_CONST;
    if (ang < 0) ang += 360.0;
    dirMedia = ((int)round(ang / 45.0) * 45) % 360;
  }

  float irradiancia = (nIrr > 0) ? somaIrr / nIrr : AUSENTE;

  // ── Monta e envia o pacote CSV ──────────────────────────────────
  String payload = montarCSV(temperatura, pressao, umidade,
                             pulsosChuva, chuva,
                             velMedia, rajadaMax,
                             dirMedia, irradiancia);

  // Envia 2x com um pequeno intervalo. Se o gateway perder o 1º pacote
  // (ex.: ocupado gravando no Firebase), o 2º recupera. O gateway
  // deduplica pelo conteúdo, então a leitura é gravada uma única vez.
  loraSerial.println(payload);
  delay(250);
  loraSerial.println(payload);

  // ── Relatório no Serial ─────────────────────────────────────────
  Serial.println("──── Médias da janela ──────────────────────────");
  Serial.print("Temperatura: "); Serial.print(temperatura); Serial.println(" °C");
  Serial.print("Pressão:     "); Serial.print(pressao);     Serial.println(" hPa");
  Serial.print("Umidade:     "); Serial.print(umidade);     Serial.println(" %");
  Serial.print("Chuva:       "); Serial.print(chuva);       Serial.println(" mm");
  Serial.print("Vento médio: "); Serial.print(velMedia);    Serial.println(" m/s");
  Serial.print("Rajada (3s): "); Serial.print(rajadaMax);   Serial.println(" m/s");
  Serial.print("Direção:     "); Serial.print(dirMedia);    Serial.println("°");
  Serial.print("Irradiância: "); Serial.print(irradiancia); Serial.println(" W/m²");
  Serial.print("Amostras BME: "); Serial.println(nBme);
  Serial.println("──── Payload enviado ───────────────────────────");
  Serial.println(payload);

  // Tempo para o LoRa terminar de transmitir antes de dormir
  delay(500);

  // ── Deep sleep ──────────────────────────────────────────────────
  Serial.println("=== DORMINDO por 3 minutos ===\n");
  Serial.flush();
  ESP.deepSleep(TEMPO_SONO);
}

void loop() {
  // Vazio — todo o ciclo acontece no setup() porque o deep sleep
  // reseta o ESP a cada despertar.
}

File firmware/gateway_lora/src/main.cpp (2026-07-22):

#include <Arduino.h>

#include <SoftwareSerial.h>
#include <ESP8266WiFi.h>
#include <Firebase_ESP_Client.h>
#include <time.h>

#include <addons/TokenHelper.h>
#include <addons/RTDBHelper.h>

// ─── Credenciais (carregadas de arquivo separado para segurança) ─────
#include "credentials.h"

FirebaseData fbdo;
FirebaseAuth auth;
FirebaseConfig config;

// ─── LoRa ────────────────────────────────────────────────────────
SoftwareSerial loraSerial(12, 13, false);

// ─── Buffer de recepção (char[] fixo) ────────────────────────────
char     rxBuffer[200];
uint16_t rxPos = 0;

// ─── Estado de inicialização do Firebase ─────────────────────────
bool firebaseIniciado = false; // signUp/begin só rodam UMA vez

// ─── Heartbeat ───────────────────────────────────────────────────
unsigned long ultimoHeartbeat = 0;
const unsigned long INTERVALO_HEARTBEAT = 15000;

// ─── Reconexão Wi-Fi NÃO-BLOQUEANTE ──────────────────────────────
void garantirWifi() {
  static unsigned long ultimaTentativa = 0;
  if (WiFi.status() == WL_CONNECTED) return;

  unsigned long agora = millis();
  if (agora - ultimaTentativa >= 5000) {
    ultimaTentativa = agora;
    Serial.println("[WiFi] Desconectado — tentando reconectar...");
    WiFi.disconnect();
    WiFi.begin(WIFI_SSID, WIFI_PASS);
  }
}

void configurarNTP() {
  configTime(-3 * 3600, 0, "pool.ntp.org", "a.ntp.br");
  Serial.print("Sincronizando hora via NTP");
  time_t agora = time(nullptr);
  int tentativas = 0;
  while (agora < 100000 && tentativas < 20) {
    delay(500); Serial.print("."); agora = time(nullptr); tentativas++;
  }
  Serial.println(agora > 100000 ? "\nHora sincronizada!" : "\nFalha no NTP.");
}

// Inicializa o Firebase UMA ÚNICA VEZ (evita o loop de INVALID_EMAIL)
void iniciarFirebaseUmaVez() {
  if (firebaseIniciado) return;
  if (WiFi.status() != WL_CONNECTED) return;

  configurarNTP();

  config.database_url = FIREBASE_HOST;
  config.api_key      = FIREBASE_API_KEY;
  config.token_status_callback = tokenStatusCallback;

  Serial.println("Criando usuário anônimo (única vez)...");
  if (Firebase.signUp(&config, &auth, "", "")) {
    Serial.println("Usuário anônimo criado!");
  } else {
    Serial.print("Falha no signUp: ");
    Serial.println(config.signer.signupError.message.c_str());
  }

  Firebase.begin(&config, &auth);
  Firebase.reconnectWiFi(true);

  firebaseIniciado = true;
  Serial.println("Firebase iniciado.");
}

String grausParaNome(int g) {
  switch (g) {
    case 315: return "Noroeste";
    case 270: return "Oeste";
    case 225: return "Sudoeste";
    case 180: return "Sul";
    case 135: return "Sudeste";
    case 90:  return "Leste";
    case 45:  return "Nordeste";
    default:  return "Norte";
  }
}

void enviarHeartbeat() {
  if (!firebaseIniciado || !Firebase.ready() || WiFi.status() != WL_CONNECTED) return;

  String path = "/estacao/status";
  time_t agora = time(nullptr);

  bool ok = true;
  ok &= Firebase.RTDB.setBool(&fbdo, path + "/online", true);
  ok &= Firebase.RTDB.setInt(&fbdo,  path + "/ultimoHeartbeat", (int)agora);

  if (ok) Serial.println("[Heartbeat] OK.");
  else { Serial.print("[Heartbeat] Erro: "); Serial.println(fbdo.errorReason()); }
}

// QC final antes de gravar (defesa em profundidade — o nó já filtra, mas
// o gateway garante que nenhuma rajada espúria chegue ao banco).
void qcVento(float &velMS, float &rajada) {
  const float LIMITE = 50.0;   // ~180 km/h: acima disso é impossível aqui
  const float FATOR  = 3.0;    // rajada plausível é no máx ~3x a média
  if (velMS > LIMITE || velMS < 0) velMS = 0;
  if (rajada > LIMITE || (velMS > 0.5 && rajada > velMS * FATOR)) rajada = velMS;
  if (rajada < velMS) rajada = velMS;
}

// Grava a leitura em /estacao/leituras E em /estacao/historico/<epoch>.
// UM setJSON por destino (rápido → menos tempo "surdo" ao LoRa; e o site
// recebe a leitura completa num evento só, não vários eventos parciais).
void enviarFirebase(float temp, float pres, float umid, int pulsos,
                    float chuva, float velMS, float rajada,
                    int dir, float irrad) {
  if (!firebaseIniciado || !Firebase.ready() || WiFi.status() != WL_CONNECTED) {
    Serial.println("[Firebase] Não pronto — pulando envio.");
    return;
  }

  qcVento(velMS, rajada);
  time_t agora = time(nullptr);

  FirebaseJson json;
  json.set("temp",      temp);
  json.set("pres",      pres);
  json.set("umid",      umid);
  json.set("pulsos",    pulsos);
  json.set("chuva",     chuva);
  json.set("velMS",     velMS);
  json.set("rajada",    rajada);
  json.set("dir",       dir);
  json.set("direcao",   grausParaNome(dir));
  json.set("irrad",     irrad);
  json.set("timestamp", (int)agora);

  if (Firebase.RTDB.setJSON(&fbdo, "/estacao/leituras", &json))
    Serial.println("[Firebase] Dados enviados!");
  else { Serial.print("[Firebase] Erro: "); Serial.println(fbdo.errorReason()); }

  String path = "/estacao/historico/" + String((uint32_t)agora);
  if (Firebase.RTDB.setJSON(&fbdo, path, &json))
    Serial.println("[Historico] Registro arquivado!");
  else { Serial.print("[Historico] Erro: "); Serial.println(fbdo.errorReason()); }
}
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

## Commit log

2026-07-11 Meteorinho via NVIDIA (proxy Cloudflare) + histórico de medições
    - meteorinho_proxy: Cloudflare Worker que faz proxy para a API da NVIDIA,
    mantendo a chave em segredo (CORS restrito ao site do totem)
    - web_app: Meteorinho passa a chamar o proxy (URL em src/config.js);
    se o proxy estiver offline/vazio, usa o cérebro local automaticamente
    - web_app: Gráficos com seletor de período (sessão / 24 h / 7 dias),
    lendo o histórico de /estacao/historico sob demanda
    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
2026-07-11 Meteorinho: usa llama-3.1-8b-instruct (baixa latencia p/ totem)
    O modelo 70B respondia em dezenas de segundos (acima do timeout de 15s
    do site). O 8B responde em ~1-2s com bom portugues para respostas curtas.
2026-07-11 Meteorinho: modelo Ministral 14B + prompt didatico rico + limpa markdown
    - Modelo mistralai/ministral-14b-instruct-2512: melhor portugues que o 8B,
    respostas em ~2s (dentro do orcamento de latencia do totem). Nemo/Qwen/
    Nemotron testados, mas nao liberados na conta NVIDIA gratuita.
    - Prompt do sistema reescrito: persona, cenario (Ouro Preto/LoRa/solar),
    regras de estilo (curto, PT-BR, sem markdown), o que sabe dos sensores
    (media OMM x rajada 3s) e guarda-corpos (nao prever, nao inventar numeros).
    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
2026-07-11 Aviso de desconexao no lugar dos dados atrasados
    Quando o receptor cai (offline) ou o no dos sensores para de enviar (aguardando), o dashboard e o modo atrativo mostram um aviso claro em vez de leituras antigas. Mensagens distintas (receptor x sens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
2026-07-13 fix: pinos do i2c remanejados para D3 e D4
    [main.cpp]
2026-07-13 fix: consertadas as janelas ativa/sleep (2/3min)
    [main.cpp]
2026-07-17 Creditos: adiciona Gustavo de Oliveira Morais
    Terceiro autor do projeto, junto com Altamiro e Tulio. Atualizado no rodape do site e no README do web_app.
2026-07-19 feature: adicionado esquematicos da placa leitor
    [.kicad_sch, leitor.kicad_pcb, leitor.kicad_sch]
2026-07-21 Status so 'online/offline': nao alarma falta de leituras dos sensores
    O receptor perde pacotes LoRa do no com frequencia (normal), entao a falta de leituras nao vira mais tela de aviso. So mostra 'Receptor fora do ar' quando o heartbeat do receptor para. A frescura dos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
2026-07-22 QC de dados (norma OMM) + confiabilidade LoRa + rotulos corretos
    FIRMWARE no: rejeita rajada espuria (cap 50 m/s + fator 3x a media, que gerava '441 km/h'); marca dado ausente do BME como -999; reenvia o pacote 2x para recuperar perdas.
    FIRMWARE gateway: grava com UM setJSON (leituras+historico) em vez de 11 escritas (menos tempo surdo ao LoRa; site recebe leitura completa num evento so); deduplica retransmissoes; QC extra de vento antes de gravar.
    SITE: sanitiza vento implausivel e sentinela -999 nos cards e graficos (esconde ate os '441 km/h' ja gravados); corrige textos que atribuiam a media de 2 min a OMM (a OMM sinotica e 10 min; so a rajada de 3 s segue a OMM).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
    [main.cpp]
2026-07-23 Adiciona arco solar: nascer/por do sol detectados pela irradiancia
    Novo painel na secao Agora mostrando o caminho do sol no ceu, com nascer, por e duracao do dia detectados dos cruzamentos de limiar (5 W/m2) na irradiancia do historico. O sol percorre o arco pelo ho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
2026-07-23 Arco solar: limiar 0 W/m2 e redesign compacto e elegante (sem emojis)
    Limiar de deteccao vai para 0 (irrad ja vem clampada >=0 no firmware), captando a primeira e a ultima luz do dia. Painel redesenhado: menor e mais discreto, arco fino com gradiente quente, sol como ponto luminoso em SVG, lua em crescente via mascara, tipografia limpa. Removidos todos os emojis (visual mais profissional).
2026-07-23 Chat aceita teclado fisico e arco solar em largura total
    Meteorinho: o campo deixa de ser readOnly, aceitando teclado fisico do celular/computador, com Enter para enviar e um botao de enviar dedicado. O teclado virtual continua disponivel pelo botao, para 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
    ArcoSolar: card passa a ocupar a largura toda, alinhado com a grade de cards (mx-4). Em telas largas o arco e os numeros ficam lado a lado; no celular, empilhados.
2026-07-23 Corrige lua durante o dia e faz o arco solar preencher o card
    BUG: com limiar 0, uma leitura zerada no meio do dia criava um 'por do sol' falso, e o sol sumia (virando lua) quando o dia passava do por estimado. Agora dia/noite vem da ULTIMA irradiancia medida (sinal direto), os cruzamentos sao agrupados por data (primeiro nascer e ultimo por do dia, imune a oscilacoes), e o por de hoje e estimado como por de ontem + 24h. O sol fica visivel o dia todo, repousando no fim do arco.
    LAYOUT: o arco passa a preencher o card inteiro (SVG normalizado que estica, com sol e pontas em HTML para seguirem redondos).
